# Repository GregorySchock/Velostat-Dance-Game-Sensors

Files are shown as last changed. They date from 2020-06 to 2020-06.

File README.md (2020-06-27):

# Velostat-Dance-Game-Sensors
A multitude of models and design files for various designs of 3D printable velostat sensors for dance games. They can be printed in normal old PLA, and only need wire, copper tape, and a strip of velostat/Linqstat. In general, all sensors will be comprised of 2 strips of copper tape on top of one another, separated by a strip of velostat, cut wide enough to prevent the copper tape from ever shorting on each other.

If building a new pad, I'd currently recommend the Azlestomp design.

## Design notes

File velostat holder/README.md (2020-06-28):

# DO NOT USE BASE OR TOP UNLESS YOU WANT AWFUL SENSORS

# Older sensors I've made

The sensors here are some of my earlier attempts at making vstat sensors. 

"Base" and "Top" are provided for historical reasons. They're the first ones I ever tried to make, and are borderline unusable. They require supports to print correctly (unless you'd want to print them vertically, but I always feared they'd crack under pressure). Due to the support removal process, they end up with a gap on one side most of the time, and are almost useless. Don't use them, lol.

"updated bottom" and "updated top" were workhorses of sensors for me for a long time. I've still got one in a pad somewhere I think. They're small, compact, and very effective. Main downside is that they have nothing to retain their sensors, so they can have their tops slide out very easily.

The v2 iterations attempted to address the top sliding out issue, they replace only the bottom half of the previous iteration, the top remains the same. The wiring was a bit difficult on these, and the clip doesn't retain the top as well as I'd hoped, unless it's glued or fused in place. Otherwise, very clean sensors.

Updated bottom/top can go into the "mini sensor arrow" model. This is a replica DDR arrow I 3D printed as a test piece while developing velostat firmware. If you want a cute DDR arrow about the size of a CD case, it's exactly what you're looking for! Secured with 4 M4 screws in the corners, and powered off 4 "updated" sensors. The V2 versions can fit, but I'm not sure about how to handle the wire management.

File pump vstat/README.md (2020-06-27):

# Pump sensor recreation
I had a PIU sensor on hand one day, and decided to try and model one up as a velostat sensor. "Sensor Finished v1" is as close to a 1:1 replica of a PIU sensor as I was able to achieve. From there, I cut it up into pieces to make into a vstat sensor.

As far as vstat sensors, I generally wouldn't recommend this one for most uses. It's not overly consistent, and its length makes it a bit tricky to get a good read most of the time. Plus, The current design doesn't accomidate for any clip or similar to retain the top half, thus I've had sensors fail more than once due to the tape I was using to retain the top weakening and having the top slide out of place. 

Theoretically, these could be used to convert a PIU pad to velostat, should someone decide to make them 1. work a bit better and 2. design a board that'd be able to handle analog reads of 20 sensors at a time and report it to a PIU-IO as if it were an original pad. SMX pads can do it, perhaps it's possible!

Arguably the most important model here is "sensor rubber". It's a similarly "close to 1:1 as I could get" model that, if printed in a flexible filament, is a drop in replacement for sensor holders on DDR/PIU pads. If your sensor rubbers are hard or broken, and you have a 3D printer and a spool of SainSmart TPU, give them a shot! I've been running them in my pads for a long time now, they work extremely well.

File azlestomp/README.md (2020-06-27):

# Azlestomp
Sensor made for someone as a drop-in replacement for their ITG pad. Made to be able to be screwed into a wooden pad.
Print all 3 parts, line a piece of 10mm copper tape or thinner along the bottom of the top and bottom. Thread a wire through the hole in the bottom, split it and run one through the hole in the top to the other side, where it should be secured with solder. The other wire should be soldered close to where it enters the bottom half. Secure with hot glue to seal. Final step, insert the "spike" piece into the end of the bottom to keep the top from sliding out (after inserting a carefully cut piece of velostat between the two). 

They're extremely sensitive, and give consistent readings. They have yet to be throughly tested long-term, but changes will be made to address issues as they arise.

TODO: Redesign to have wires exit on a more conventional side, like seen in traditional arcade sensors. Clip needs to be redone, as currently they're a bit fragile and need to be fused in place with a soldering iron or similar to be secure at the moment.

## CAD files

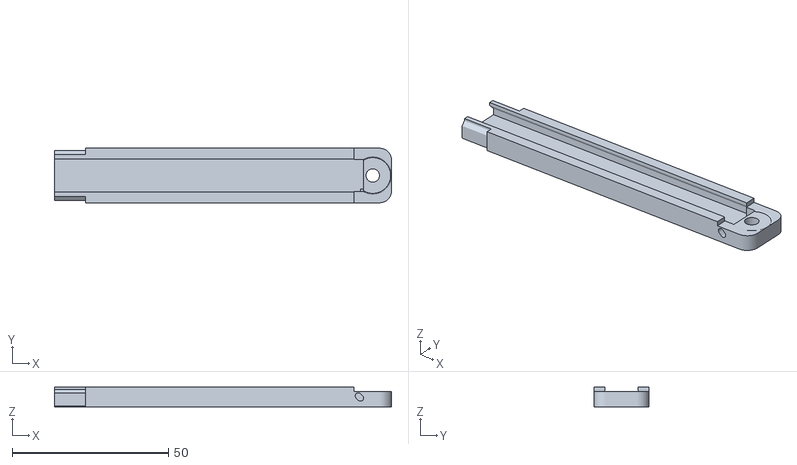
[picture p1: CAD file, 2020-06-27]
azlestomp/bottom v2.stl
108.0 x 17.5 x 6.40

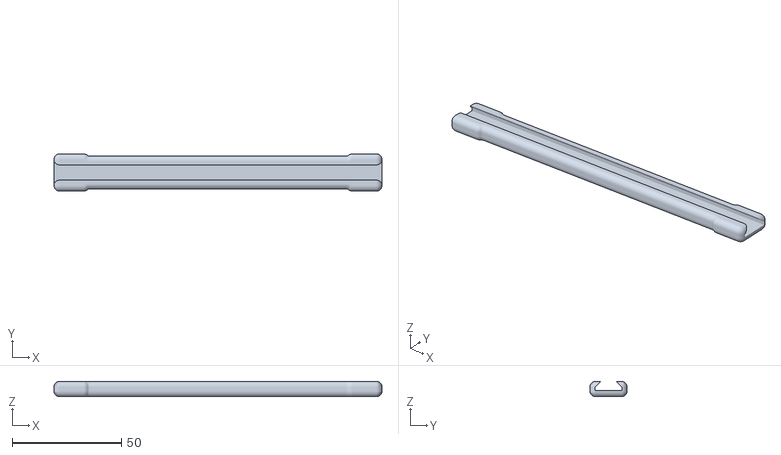
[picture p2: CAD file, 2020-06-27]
pump vstat/pump vstat bottom.stl
150.0 x 17.0 x 7.00

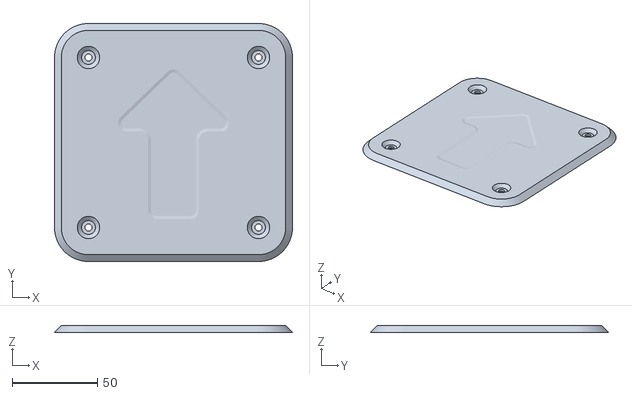
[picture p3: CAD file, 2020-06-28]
velostat holder/mini sensor arrow top.stl
140.0 x 140.0 x 4.00

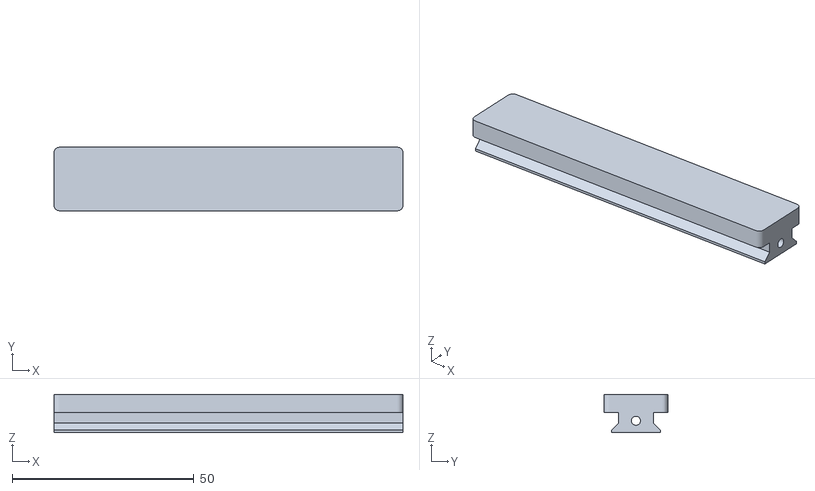
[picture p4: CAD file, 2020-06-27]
azlestomp/top v3.stl
96.0 x 17.5 x 10.5

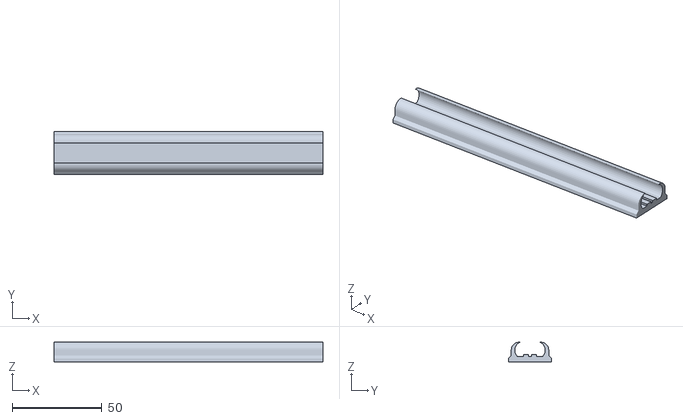
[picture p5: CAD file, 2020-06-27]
pump vstat/sensor rubber.stl
150.0 x 24.0 x 11.0

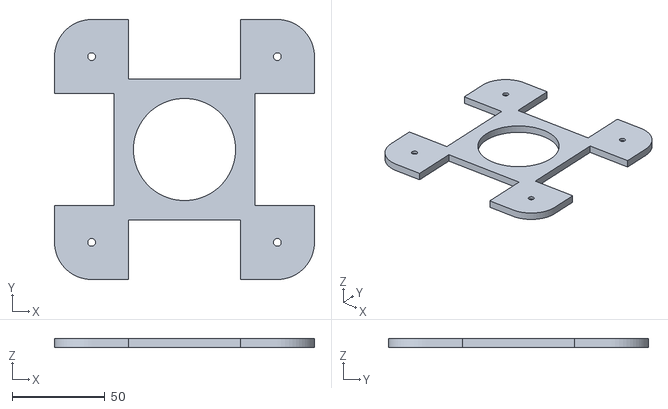
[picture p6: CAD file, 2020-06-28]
velostat holder/mini sensor arrow bottom.stl
140.0 x 140.0 x 5.00

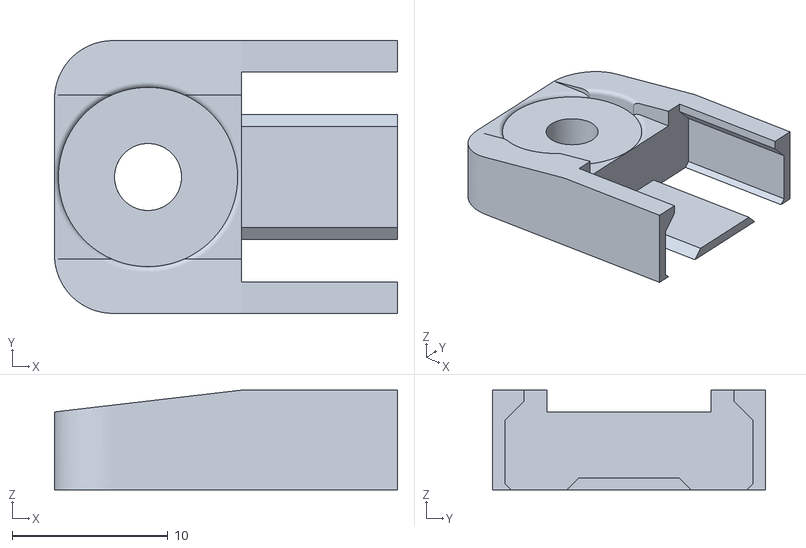
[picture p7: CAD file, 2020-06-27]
azlestomp/spike boi.stl
22.0 x 17.5 x 6.40

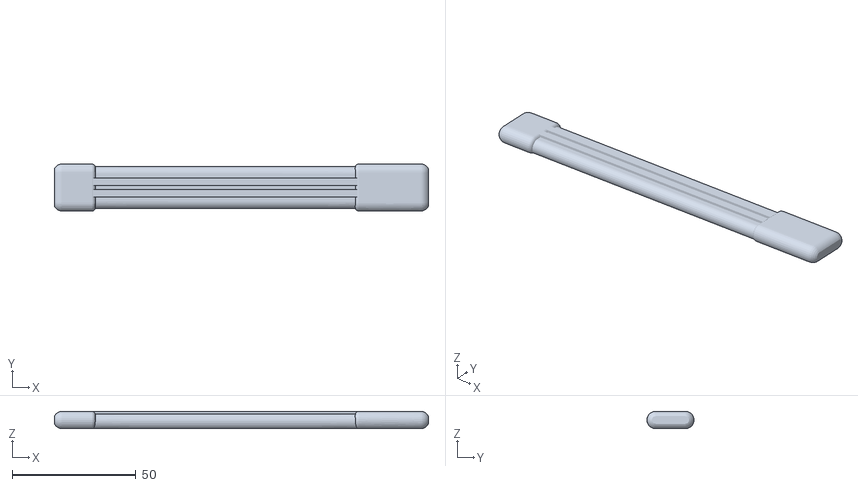
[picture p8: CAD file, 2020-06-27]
pump vstat/Sensor finished v1.stl
151.3 x 19.1 x 7.00

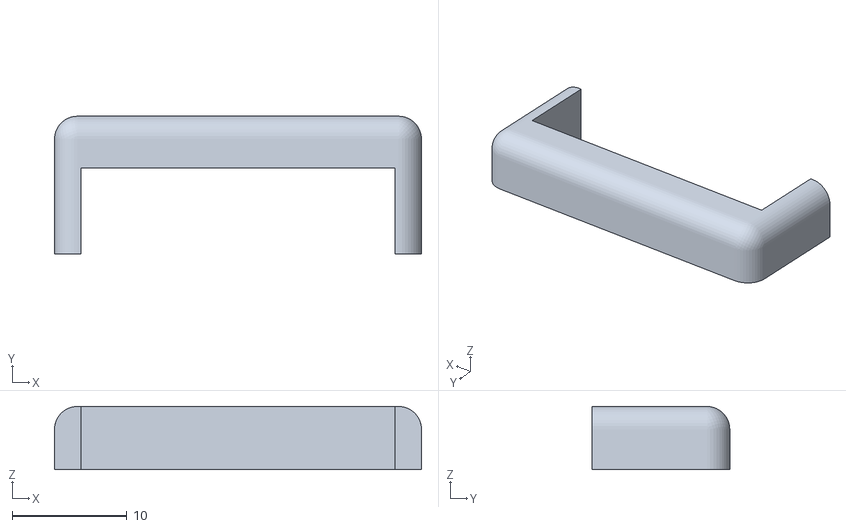
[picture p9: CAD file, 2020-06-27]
velostat holder/updated retaining clip, for v2.stl
32.0 x 12.0 x 5.50

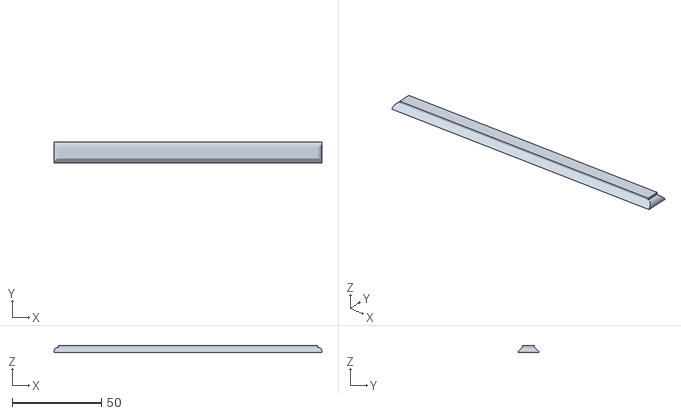
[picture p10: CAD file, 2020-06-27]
pump vstat/pump vstat top.stl
150.0 x 12.0 x 3.96

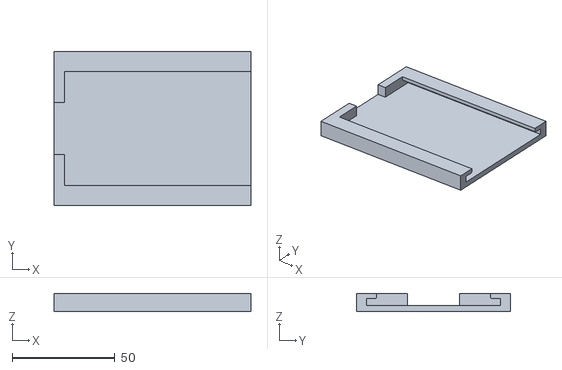
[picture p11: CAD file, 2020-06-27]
velostat holder/base.stl
96.0 x 75.0 x 9.00

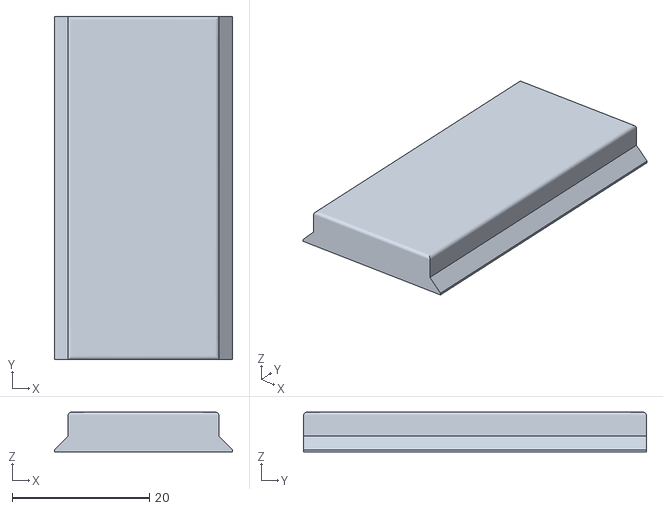
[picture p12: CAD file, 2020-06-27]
velostat holder/updated top.stl
26.0 x 50.0 x 5.80

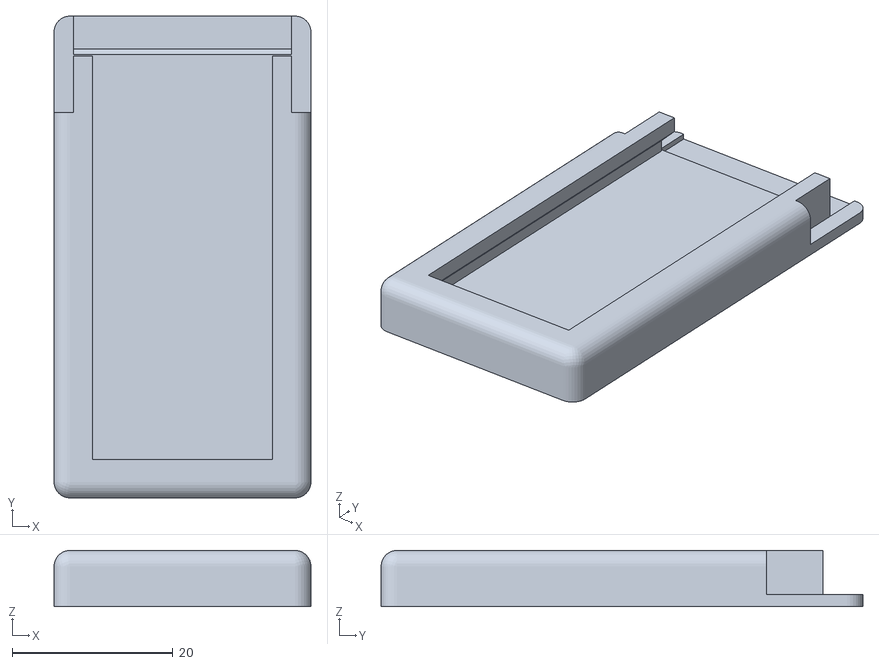
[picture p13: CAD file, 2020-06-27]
velostat holder/updated bottom v2.stl
32.0 x 60.0 x 7.00

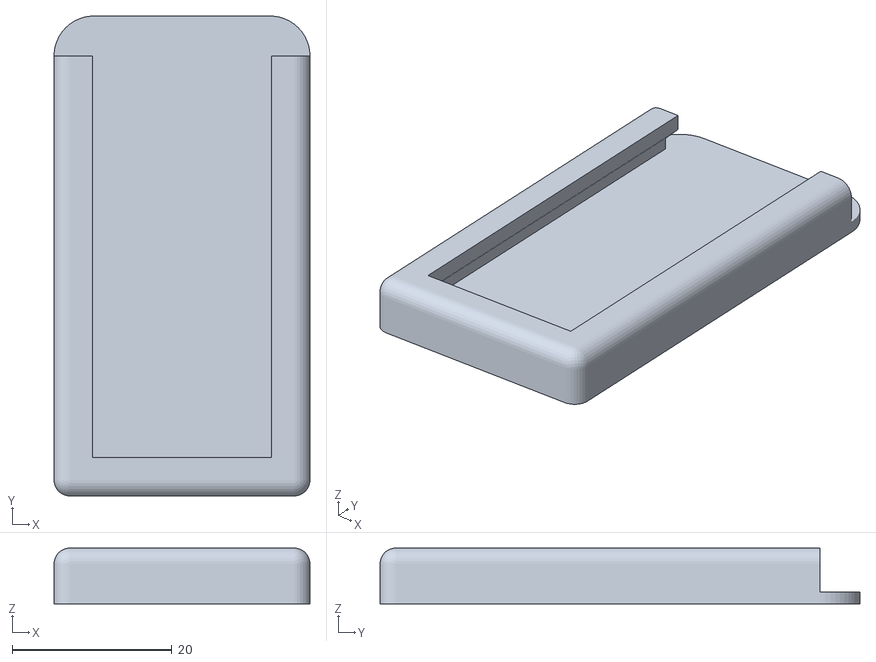
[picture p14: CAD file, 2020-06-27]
velostat holder/updated bottom.stl
32.0 x 60.0 x 7.00

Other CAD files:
velostat holder/top.stl
azlestomp/Azlestomp vstat sensor v4.f3d
pump vstat/velostat sensor v1.f3d

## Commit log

2020-06-27 Add files via upload
    Added CAD file for initial release. Be warned, there's quite a few grimy shortcuts I take, and in future iterations I'm likely to scrap the current version and make a new one based off of some of the measurements and not much else.
    [Azlestomp vstat sensor v4.f3d]
2020-06-27 Add files via upload
    Older models I made
    [base.stl, top.stl, updated bottom v2.stl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]
2020-06-28 Added mini sensor arrow, updated readme to explain
    [mini sensor arrow bottom.stl, mini sensor arrow top.stl]
